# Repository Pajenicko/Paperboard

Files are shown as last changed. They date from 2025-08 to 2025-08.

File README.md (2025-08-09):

# Paperboard

Paperboard is an ESP32-based e-paper display controller firmware designed for easy dashboard creation and display management. The project provides a ready-to-use solution for driving e-paper displays with custom content.

## Features

- ESP32-based e-paper display controller
- Support for various e-paper display sizes and types
- Custom firmware optimized for dashboard applications
- Integration-ready for web services

## zivyobraz.eu Integration

This firmware is specifically prepared to work seamlessly with [zivyobraz.eu](https://zivyobraz.eu), a web service that offers really easy drag-and-drop design of custom dashboards. Simply upload your firmware and start creating beautiful dashboards without any programming knowledge required.

## epdiy Library

The project includes a modified version of the excellent [epdiy library](https://github.com/vroland/epdiy) to ensure optimal compatibility with the Paperboard hardware. A pull request will soon be opened to include our board support in the main epdiy library. Once that happens, we can switch to using the pure library via platformio.ini configuration.

## License

The epdiy library components are licensed under the GNU Lesser General Public License v3 (LGPL-3.0). See the `lib/epdiy/LICENSE` file for full license details.

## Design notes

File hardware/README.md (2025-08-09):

# Paperboard Hardware

This directory contains the hardware design files for the Paperboard e-paper display controller.

## Design Basis

The Paperboard hardware is based on the [epdiy-v7](https://github.com/vroland/epdiy-hardware) design, which provides an excellent foundation for e-paper display controllers. We've made specific modifications to optimize the board for our use case while maintaining compatibility with the epdiy ecosystem.

## Files Included

- KiCad project files and schematics
- Component libraries and footprints
- PCB layout design
- Schematic PDF documentation

## License and Attribution

This hardware design is derived from the [epdiy-hardware](https://github.com/vroland/epdiy-hardware.git) project and is licensed under the **Creative Commons Attribution-ShareAlike 4.0 International License**.

### Attribution

- **Original Work**: epdiy-v7 hardware design
- **Original Author**: vroland and contributors
- **Source**: https://github.com/vroland/epdiy-hardware.git
- **Modifications**: Adapted for Paperboard requirements

### License Terms

You are free to:
- **Share** — copy and redistribute the material in any medium or format
- **Adapt** — remix, transform, and build upon the material for any purpose, even commercially

Under the following terms:
- **Attribution** — You must give appropriate credit, provide a link to the license, and indicate if changes were made. You may do so in any reasonable manner, but not in any way that suggests the licensor endorses you or your use.
- **ShareAlike** — If you remix, transform, or build upon the material, you must distribute your contributions under the same license as the original.

### Full License

The complete license text can be found at: https://creativecommons.org/licenses/by-sa/4.0/

### Copyright Notice

This work is licensed under a Creative Commons Attribution-ShareAlike 4.0 International License.

To view a copy of this license, visit http://creativecommons.org/licenses/by-sa/4.0/ or send a letter to Creative Commons, PO Box 1866, Mountain View, CA 94042, USA.

## Using This Design

When using or modifying this design, please ensure you:
1. Provide proper attribution as outlined above
2. Share any derivative works under the same CC BY-SA 4.0 license
3. Clearly indicate any modifications made to the original design
4. Include this license information with any distributions

## Compliance

This hardware design complies with the Creative Commons Attribution-ShareAlike 4.0 International License requirements for derivative works based on the original epdiy-hardware project.

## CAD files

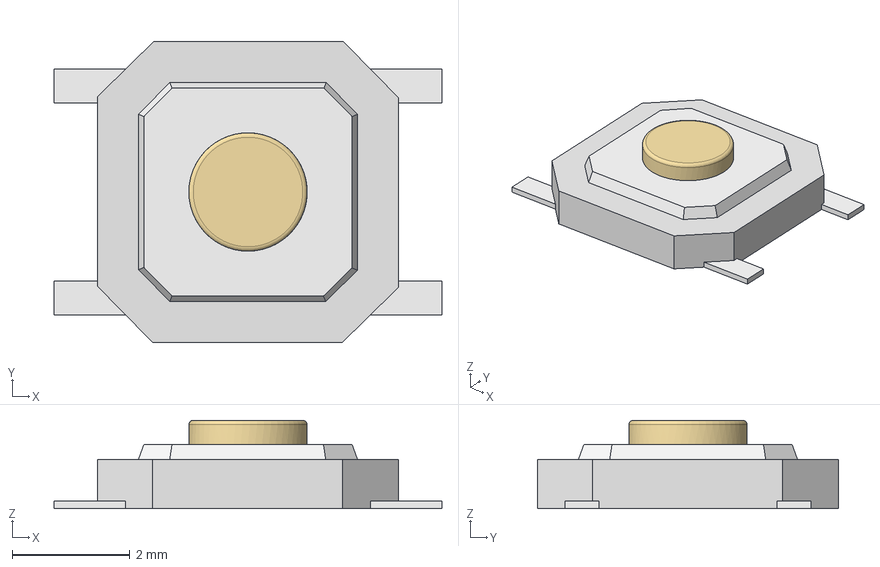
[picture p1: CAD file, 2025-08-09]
hardware/kicad/Tactal Switch - SMD (5mmx 5mmx1.5mm).stp
6.58 x 5.10 x 1.50 mm

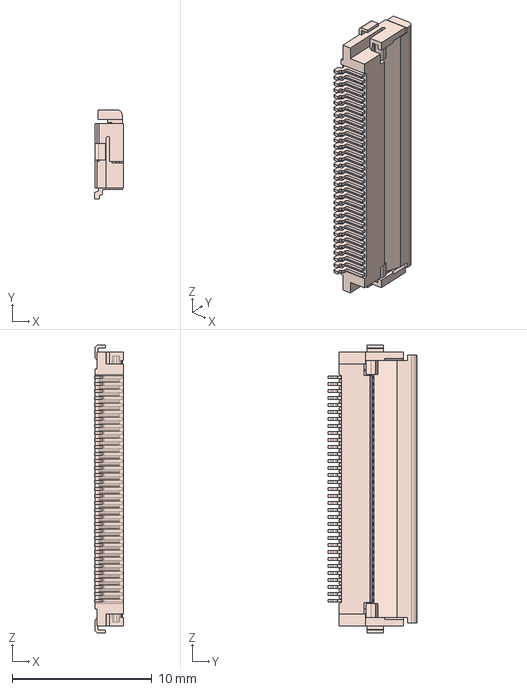
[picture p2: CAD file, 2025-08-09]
hardware/kicad/FH12-33S-0.5SH.stp
2.10 x 6.40 x 20.6 mm

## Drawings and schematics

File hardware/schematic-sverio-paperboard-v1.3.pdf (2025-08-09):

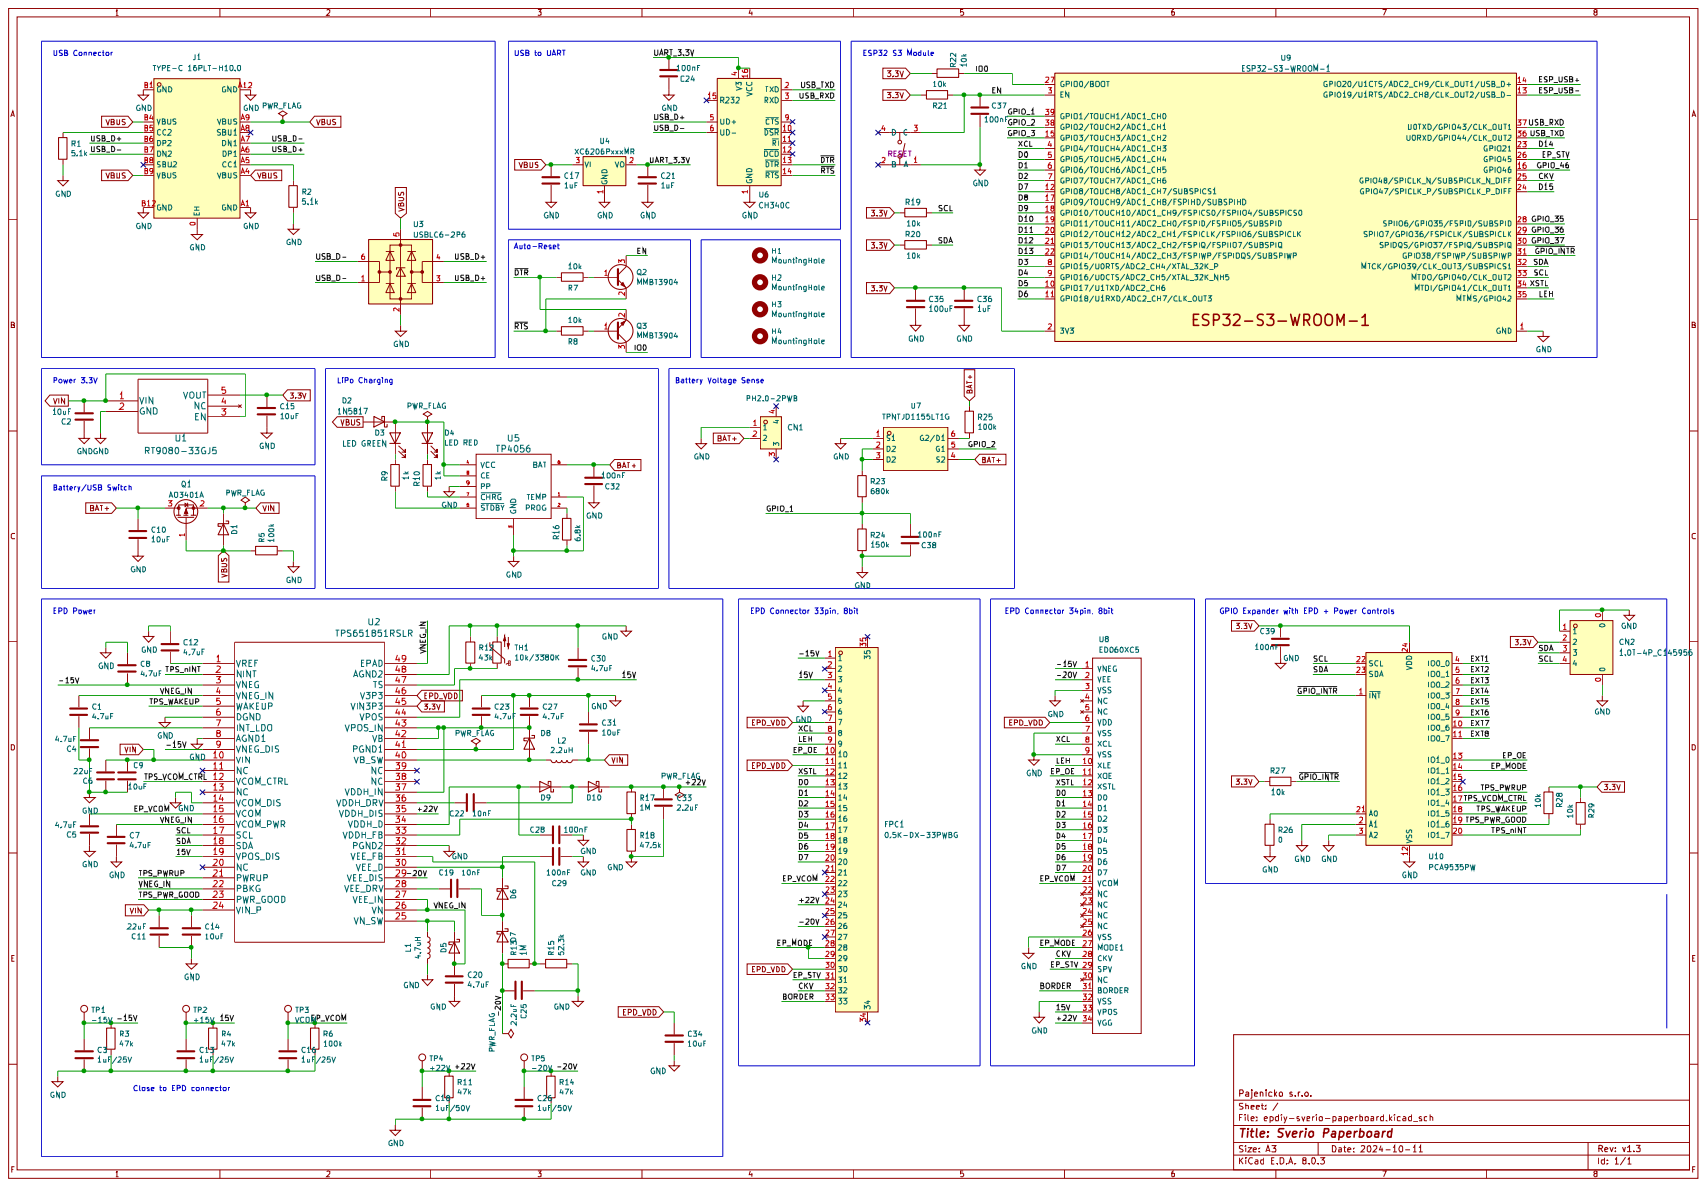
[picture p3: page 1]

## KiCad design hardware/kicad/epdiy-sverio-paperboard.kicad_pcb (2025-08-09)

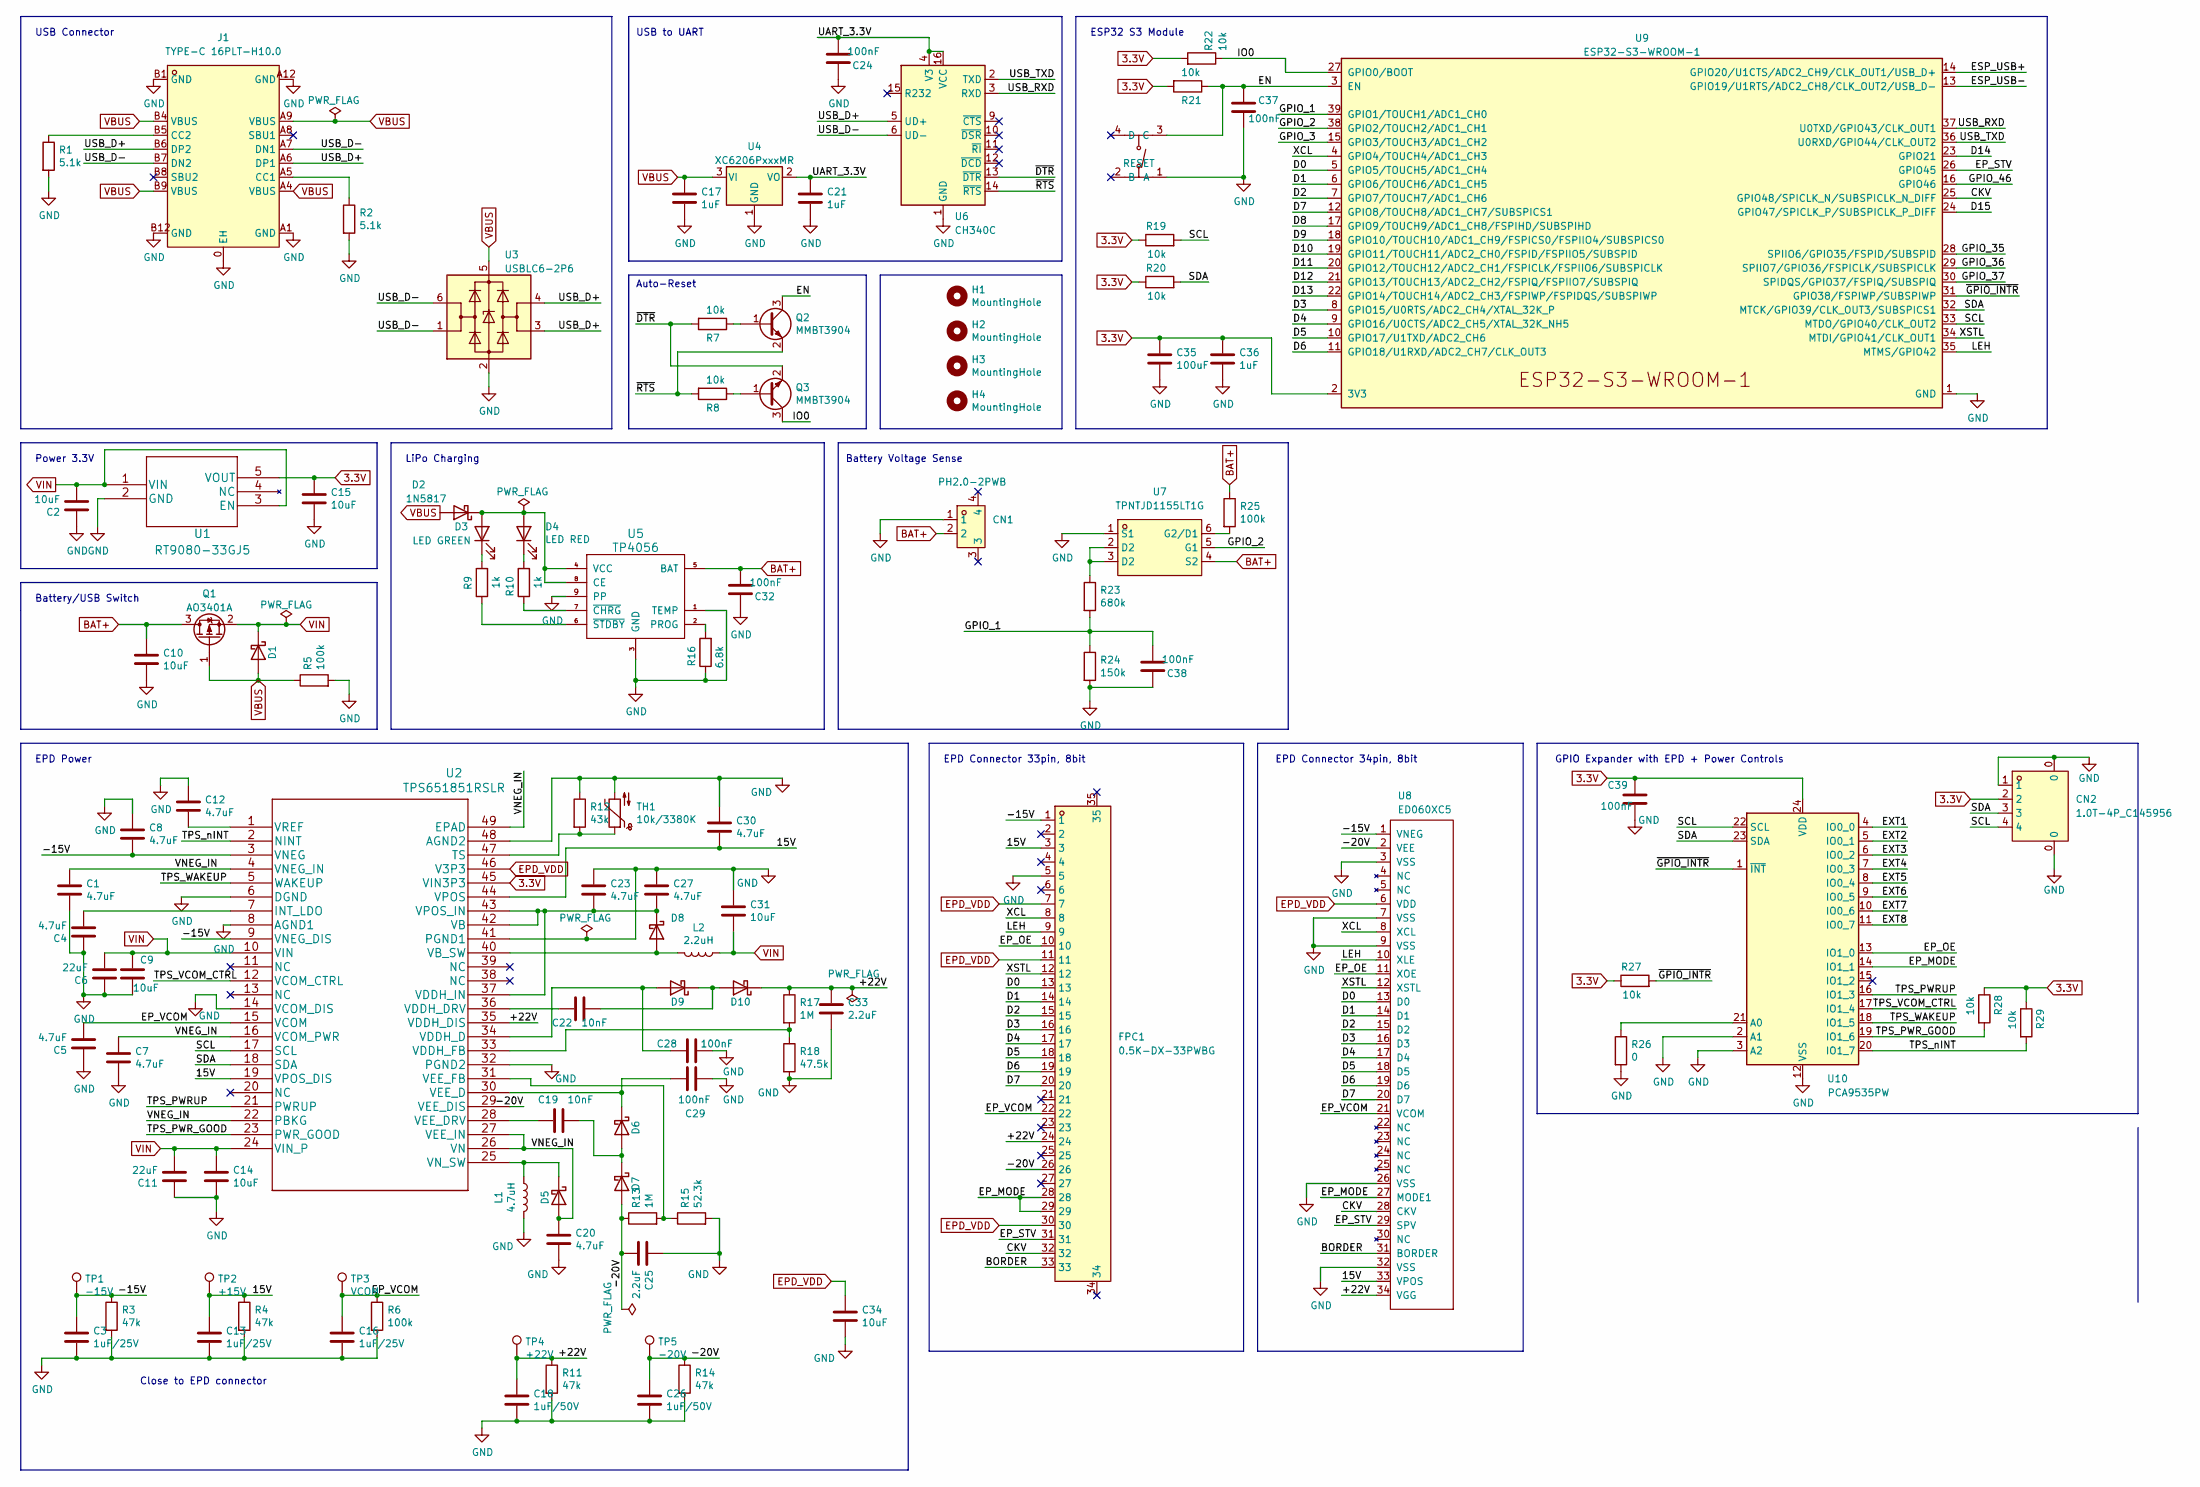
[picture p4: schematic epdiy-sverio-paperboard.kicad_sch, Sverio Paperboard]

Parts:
C1, C4, C5, C7, C8, C12, C20, C23, C27, C30: 4.7uF; C_0805_2012Metric; LCSC C1779
C2, C9, C10, C14, C15, C31, C34: 10uF; C_0805_2012Metric; LCSC C15850
C3, C13, C16: 1uF/25V; C_0805_2012Metric; LCSC C28323
C6, C11: 22uF; C_0805_2012Metric; LCSC C45783
C17, C21, C36: 1uF; C_0805_2012Metric; LCSC C28323
C18, C26: 1uF/50V; C_1206_3216Metric; LCSC C1848
C19, C22: 10nF; C_0805_2012Metric; LCSC C1710
C24, C28, C29, C32, C37, C38, C39: 100nF; C_0805_2012Metric; LCSC C49678
C25, C33: 2.2uF; C_0805_2012Metric; LCSC C49217
C35: 100uF; CP_EIA-3528-15_AVX-H; LCSC C16133
CN1: PH2.0-2PWB; CONN-SMD_2P-P2.00_PH2.0-SPWB; LCSC Part C47647
CN2: 1.0T-4P_C145956; CONN-SMD_1.0T-4P; LCSC Part C145956
D1, D5, D6, D7, D8, D9, D10: MBR0540; D_SOD-123; LCSC C21353
D2: 1N5817; D_SOD-123; LCSC C8598
D3: LED GREEN; LED_0805_2012Metric; LCSC C2297
D4: LED RED; LED_0805_2012Metric; LCSC C84256
FPC1: 0.5K-DX-33PWBG; FPC-SMD_33P-P0.50_HDGC_0.5K-DX-33PWBG; LCSC Part C2911902
H1, H2, H3, H4: MountingHole; MountingHole_2.2mm_M2
J1: TYPE-C 16PLT-H10.0; TYPE-C-SMD_USB4120-03-C; LCSC Part C3151749
L1: 4.7uH; L_Taiyo-Yuden_NR-50xx_HandSoldering; LCSC C222947
L2: 2.2uH; L_Taiyo-Yuden_NR-40xx_HandSoldering; LCSC C92959
Q1: AO3401A; SOT-23; LCSC C15127
Q2, Q3: MMBT3904; SOT-23; LCSC C20526
R1, R2: 5.1k; R_0603_1608Metric; LCSC C23186
R3, R4, R11, R14: 47k; R_0603_1608Metric; LCSC C25819
R5, R6, R25: 100k; R_0603_1608Metric; LCSC C25803
R7, R8, R19, R20, R21, R22, R27, R28, R29: 10k; R_0603_1608Metric; LCSC C25804
R9, R10: 1k; R_0603_1608Metric; LCSC C21190
R12: 43k; R_0603_1608Metric; LCSC C23172
R13, R17: 1M; R_0603_1608Metric; LCSC C22935
R15: 52.3k; R_0603_1608Metric; LCSC C23196
R16: 6.8k; R_0603_1608Metric; LCSC C23212
R18: 47.5k; R_0603_1608Metric; LCSC C25819
R23: 680k; R_0603_1608Metric; LCSC C25822
R24: 150k; R_0603_1608Metric; LCSC C22807
R26: 0; R_0603_1608Metric; LCSC C21189
RESET1: TS-1187A-B-A-B; SW-SMD_4P-L5.1-W5.1-P3.70-LS6.5-TL-2; LCSC Part C318884
TH1: 10k/3380K; R_0603_1608Metric; LCSC C76589
TP1: -15V; TestPoint_Pad_D2.5mm
TP2: +15V; TestPoint_Pad_D2.5mm
TP3: VCOM; TestPoint_Pad_D2.5mm
TP4: +22V; TestPoint_Pad_D2.5mm
TP5: -20V; TestPoint_Pad_D2.5mm
U1: RT9080-33GJ5; TSOT-23-5; LCSC C841192
U2: TPS651851RSLR; LCSC C139292
U3: USBLC6-2P6; SOT-666; LCSC C2827693
U4: XC6206PxxxMR; SOT-23-3; LCSC C5446
U5: TP4056; TP4056_SOP-8-PP; LCSC C16581
U6: CH340C; SOIC-16_3.9x9.9mm_P1.27mm; LCSC C84681
U7: TPNTJD1155LT1G; SOT-363-6_L2.0-W1.3-P0.65-LS2.1-BL; LCSC Part C5246385
U8: ED060XC5; X05A20H34G; LCSC C528053
U9: ESP32-S3-WROOM-1; LCSC C2913202
U10: PCA9535PW; TSSOP-24_4.4x7.8mm_P0.65mm; LCSC C255606

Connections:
3.3V: C15.2, C35.1, C36.2, C39.1, CN2.2, R19.1, R20.1, R21.2, R22.2, R27.1, R28.1, R29.1, U1.5 (VOUT), U2.45 (VIN3P3), U9.2 (3V3), U10.24 (VDD)
/15V: C13.1, C30.2, FPC1.3, R4.1, TP2.1, U2.19 (VPOS_DIS), U2.44 (VPOS), U8.33 (VPOS)
/+22V: C18.1, C33.1, D10.1 (K), FPC1.24, R11.1, R17.1, TP4.1, U2.35 (VDDH_DIS), U8.34 (VGG)
/-15V: C3.1, C8.2, FPC1.1, R3.1, TP1.1, U2.3 (VNEG), U2.9 (VNEG_DIS), U8.1 (VNEG)
/-20V: C25.2, C26.1, D7.2 (A), FPC1.26, R13.1, R14.1, TP5.1, U2.29 (VEE_DIS), U8.2 (VEE)
/BORDER: FPC1.33, U8.31 (BORDER)
/CKV: FPC1.32, U8.28 (CKV), U9.25 (GPIO48/SPICLK_N/SUBSPICLK_N_DIFF)
/D0: FPC1.13, U8.13 (D0), U9.5 (GPIO5/TOUCH5/ADC1_CH4)
/D1: FPC1.14, U8.14 (D1), U9.6 (GPIO6/TOUCH6/ADC1_CH5)
/D2: FPC1.15, U8.15 (D2), U9.7 (GPIO7/TOUCH7/ADC1_CH6)
/D3: FPC1.16, U8.16 (D3), U9.8 (GPIO15/U0RTS/ADC2_CH4/XTAL_32K_P)
/D4: FPC1.17, U8.17 (D4), U9.9 (GPIO16/U0CTS/ADC2_CH5/XTAL_32K_NH5)
/D5: FPC1.18, U8.18 (D5), U9.10 (GPIO17/U1TXD/ADC2_CH6)
/D6: FPC1.19, U8.19 (D6), U9.11 (GPIO18/U1RXD/ADC2_CH7/CLK_OUT3)
/D7: FPC1.20, U8.20 (D7), U9.12 (GPIO8/TOUCH8/ADC1_CH7/SUBSPICS1)
/D8: U9.17 (GPIO9/TOUCH9/ADC1_CH8/FSPIHD/SUBSPIHD)
/D9: U9.18 (GPIO10/TOUCH10/ADC1_CH9/FSPICS0/FSPIIO4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)
/D10: U9.19 (GPIO11/TOUCH11/ADC2_CH0/FSPID/FSPIIO5/S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)
/D11: U9.20 (GPIO12/TOUCH12/ADC2_CH1/FSPICLK/FSPIIO6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)
/D12: U9.21 (GPIO13/TOUCH13/ADC2_CH2/FSPIQ/FSPIIO7/S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)
/D13: U9.22 (GPIO14/TOUCH14/ADC2_CH3/FSPIWP/FSPIDQS/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)
/D14: U9.23 (GPIO21)
/D15: U9.24 (GPIO47/SPICLK_P/SUBSPICLK_P_DIFF)
/EN: C37.1, Q2.3 (C), R21.1, RESET1.3 (C), U9.3 (EN)
/EP_MODE: FPC1.28, FPC1.29, U8.27 (MODE1), U10.14 (IO1_1)
/EP_OE: FPC1.10, U8.11 (XOE), U10.13 (IO1_0)
/EP_STV: FPC1.31, U8.29 (SPV), U9.26 (GPIO45)
/EP_VCOM: C5.2, C16.1, FPC1.22, R6.1, TP3.1, U2.15 (VCOM), U8.21 (VCOM)
/ESP_USB+: U9.14 (GPIO20/U1CTS/ADC2_CH9/CLK_OUT1/USB_D+)
/ESP_USB-: U9.13 (GPIO19/U1RTS/ADC2_CH8/CLK_OUT2/USB_D-)
/EXT1: U10.4 (IO0_0)
/EXT2: U10.5 (IO0_1)
/EXT3: U10.6 (IO0_2)
/EXT4: U10.7 (IO0_3)
/EXT5: U10.8 (IO0_4)
/EXT6: U10.9 (IO0_5)
/EXT7: U10.10 (IO0_6)
/EXT8: U10.11 (IO0_7)
/GPIO_1: C38.2, R23.2, R24.1, U9.39 (GPIO1/TOUCH1/ADC1_CH0)
/GPIO_2: U7.5 (G1), U9.38 (GPIO2/TOUCH2/ADC1_CH1)
/GPIO_3: U9.15 (GPIO3/TOUCH3/ADC1_CH2)
/GPIO_35: U9.28 (SPIIO6/GPIO35/FSPID/SUBSPID)
/GPIO_36: U9.29 (SPIIO7/GPIO36/FSPICLK/SUBSPICLK)
/GPIO_37: U9.30 (SPIDQS/GPIO37/FSPIQ/SUBSPIQ)
/GPIO_46: U9.16 (GPIO46)
/IO0: Q3.3 (C), R22.1, U9.27 (GPIO0/BOOT)
/LEH: FPC1.9, U8.10 (XLE), U9.35 (MTMS/GPIO42)
/SCL: CN2.4, R19.2, U2.17 (SCL), U9.33 (MTDO/GPIO40/CLK_OUT2), U10.22 (SCL)
/SDA: CN2.3, R20.2, U2.18 (SDA), U9.32 (MTCK/GPIO39/CLK_OUT3/SUBSPICS1), U10.23 (SDA)
/TPS_PWRUP: U2.21 (PWRUP), U10.16 (IO1_3)
/TPS_PWR_GOOD: R28.2, U2.23 (PWR_GOOD), U10.19 (IO1_6)
/TPS_VCOM_CTRL: U2.12 (VCOM_CTRL), U10.17 (IO1_4)
/TPS_WAKEUP: U2.5 (WAKEUP), U10.18 (IO1_5)
/TPS_nINT: R29.2, U2.2 (NINT), U10.20 (IO1_7)
/UART_3.3V: C21.2, C24.2, U4.2 (VO), U6.4 (V3), U6.16 (VCC)
/USB_D+: J1.A6 (DP1), J1.B6 (DP2), U3.3 (I/O2), U3.4 (I/O2), U6.5 (UD+)
/USB_D-: J1.A7 (DN1), J1.B7 (DN2), U3.1 (I/O1), U3.6 (I/O1), U6.6 (UD-)
/USB_RXD: U6.3 (RXD), U9.37 (U0TXD/GPIO43/CLK_OUT1)
/USB_TXD: U6.2 (TXD), U9.36 (U0RXD/GPIO44/CLK_OUT2)
/VNEG_IN: C1.1, C7.1, C20.1, D5.2 (A), U2.4 (VNEG_IN), U2.16 (VCOM_PWR), U2.22 (PBKG), U2.26 (VN), U2.27 (VEE_IN), U2.49 (EPAD)
/XCL: FPC1.8, U8.8 (XCL), U9.4 (GPIO4/TOUCH4/ADC1_CH3)
/XSTL: FPC1.12, U8.12 (XSTL), U9.34 (MTDI/GPIO41/CLK_OUT1)
/~DTR: Q3.2 (E), R7.2, U6.13 (~DTR)
/~GPIO_INTR: R27.2, U9.31 (GPIO38/FSPIWP/SUBSPIWP), U10.1 (~INT)
/~RTS: Q2.2 (E), R8.2, U6.14 (~RTS)
BAT+: C10.2, C32.2, CN1.2, Q1.3 (D), R25.1, U5.5 (BAT), U7.4 (S2)
EPD_VDD: C34.1, FPC1.7, FPC1.11, FPC1.30, U2.46 (V3P3), U8.6 (VDD)
unnamed: D2.1 (K), D3.2 (A), D4.2 (A), U5.4 (VCC), U5.8 (CE)
unnamed: D3.1 (K), R9.2
unnamed: D4.1 (K), R10.2
unnamed: D5.1 (K), L1.1, U2.25 (VN_SW)
unnamed: C19.1, D6.2 (A), D7.1 (K)
unnamed: C29.1, D6.1 (K), U2.30 (VEE_D)
unnamed: D8.2 (A), L2.2, U2.40 (VB_SW)
unnamed: C23.2, C27.2, D8.1 (K), U2.37 (VDDH_IN), U2.42 (VB), U2.43 (VPOS_IN)
unnamed: C28.2, D9.2 (A), U2.34 (VDDH_D)
unnamed: C22.1, D9.1 (K), D10.2 (A)
unnamed: J1.A5 (CC1), R2.1
unnamed: J1.B5 (CC2), R1.1
unnamed: Q2.1 (B), R7.1
unnamed: Q3.1 (B), R8.1
unnamed: R23.1, U7.2 (D2), U7.3 (D2)
unnamed: C4.2, U2.7 (INT_LDO)
unnamed: R12.2, TH1.1, U2.47 (TS)
unnamed: C22.2, U2.36 (VDDH_DRV)
unnamed: R17.2, R18.1, U2.33 (VDDH_FB)
unnamed: C19.2, U2.28 (VEE_DRV)
unnamed: R13.2, R15.1, U2.31 (VEE_FB)
unnamed: C12.2, U2.1 (VREF)
unnamed: R16.2, U5.2 (PROG)
unnamed: R10.1, U5.7 (~CHRG)
unnamed: R9.1, U5.6 (~STDBY)
unnamed: R25.2, U7.6 (G2/D1)
unnamed: R26.1, U10.21 (A0)
VIN: C2.1, C6.2, C9.1, C11.2, C14.1, C31.2, D1.1 (K), L2.1, Q1.2 (S), U1.1 (VIN), U1.3 (EN), U2.10 (VIN), U2.24 (VIN_P)

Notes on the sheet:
Battery Voltage Sense
EPD Power
GPIO Expander with EPD + Power Controls
USB Connector
ESP32 S3 Module
Power 3.3V
Auto-Reset
Battery/USB Switch
USB to UART
EPD Connector 34pin, 8bit
EPD Connector 33pin, 8bit
LiPo Charging
Close to EPD connector

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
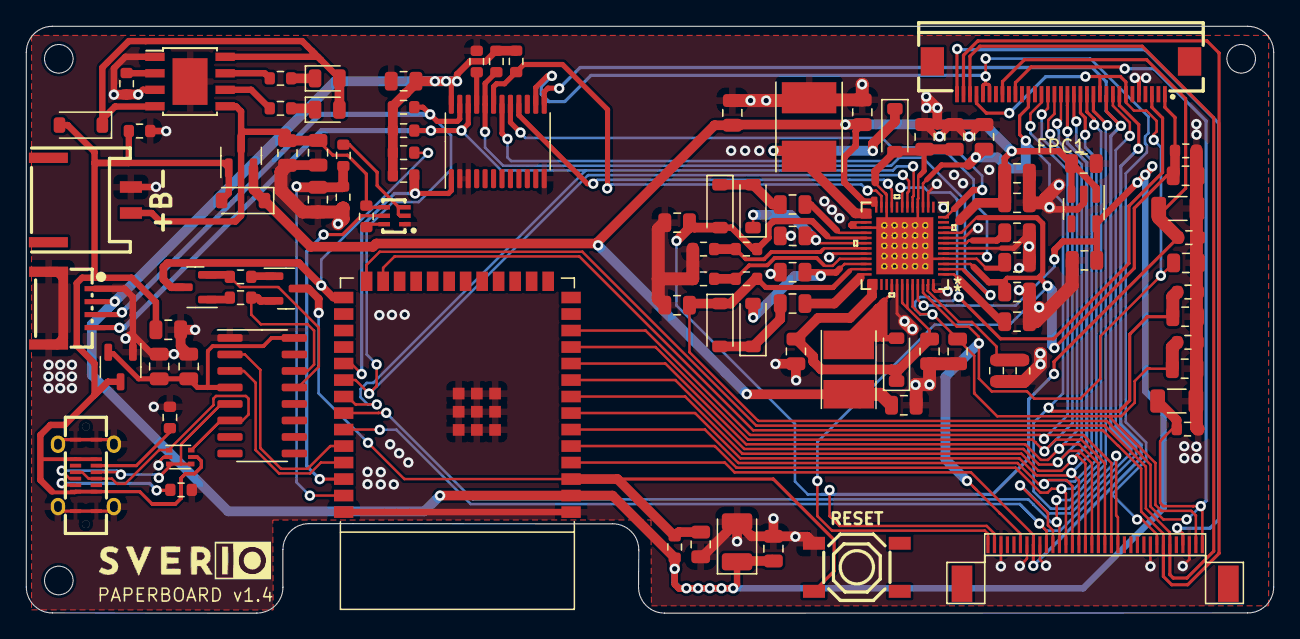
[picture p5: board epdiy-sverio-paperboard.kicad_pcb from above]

Board: 4 copper layers, 96.0 x 45.2 mm, 102 parts (0 on the bottom side), 74 nets.

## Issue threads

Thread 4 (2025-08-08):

epdiy

martinberlin, 2025-08-08:
Hello @Pajenicko
Here Martin long time collaborator of epdiy repository. I have some recommendation that you should consider:

1. Can you please use platformio.ini to link the library?
That way you can be at the latest stand. using [lib_deps](https://docs.platformio.org/en/latest/projectconf/sections/env/options/library/lib_deps.html) you could even fix it to a certain release of epdiy if you want it.  But cloning epdiy [directly into your codebase](https://github.com/Pajenicko/Paperboard/tree/main/lib/epdiy) is really not the best option since you are forcing users of this repository to download a huge library that is really not part of your firmware

2. Is possible that you also make a hardware repository to upload your epdiy clone PCB?
I guess is on your plans already but that way you complain with the [CC-BY-SA 4.0 (#31)](https://github.com/vroland/epdiy-hardware/blob/main/LICENSE) that asks everyone to do derivative work, specially when it's a commercial PCB that you will sell, to also open-source and mention clearly what is the source of the design.

Thanks a lot to take this in consideration

Pajenicko, 2025-08-08:
Hello @martinberlin!

1. Sure, that’s a good point — I’ll switch to using platformio.ini with lib_deps instead of cloning epdiy directly. I’ll also prepare a PR for the src/board/sverio_paperboard_v1.c file, that's needed to be merged beforehand.

2. Absolutely, no problem. It was my intention from the start, but I haven’t gotten around to finishing it yet (even the README.md is still a bit sad). I’ll take care of creating a separate hardware repository over the weekend, including proper attribution and licensing under CC-BY-SA 4.0.

Thanks for the reminder and pointing these out!

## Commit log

2025-05-28 Support for optional sensors SHT40/41/45, SCD40/41 and BME280.
2025-05-30 Update main.cpp
    Set the default behaviour to disable sensor detection.
2025-08-09 adding hardware folder
    [FH12-33S-0.5SH.stp, Tactal Switch - SMD (5mmx 5mmx1.5mm).stp, epdiy-sverio-paperboard.kicad_pcb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]
2026-05-15 Mark repository as obsolete, redirect to new homes
    The firmware and epdiy fork content of this repo has moved to dedicated
    repositories. The README now points to:
    - Pajenicko/sverio-paperboard-examples — peripheral-module examples
    - MultiTricker/zivyobraz-fw — zivyobraz.eu integration firmware
    - Pajenicko/epdiy — epdiy fork with sverio_paperboard_v1 board
    The hardware/ directory and its design files remain unchanged.

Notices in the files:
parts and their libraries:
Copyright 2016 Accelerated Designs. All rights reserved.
